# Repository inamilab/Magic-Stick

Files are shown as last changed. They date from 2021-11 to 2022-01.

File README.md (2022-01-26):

# Rolling Stone Illusion
This project is just a demo for the rolling stone illusion. 

## Hardware
Interface Image



This is the hardware requiered to build a rolling stone stick
- Stick: Any drum stick or aluminium stick is OK
- Microcontroller: Arduino UNO or MEGA is OK. 
- Accelerometer: MPU 6050 (https://www.amazon.co.jp/-/en/MPU-6050-3-Axis-Gyroscope-Acceleration-Sensor/dp/B008BOPN40)
- Audio Amplifier: Hapbeat Amplifier. (but any audio amplifier is OK) 
- Vibrator, serveral actuators can be used:
    - Hapbeat motor (not good)
    - ALPS transducers (available in the lab) GOOD
    - Haptuator (also available at the lab) NOT TESTED YET

### Connection PINs (Arduino pro mini)

Arduino Mini Pro pinout

Arduino PIN | Conection
--- | ---
SCL (pin D21) |  Accelerometer SCL pin
SDA (pin D20) |  Accelerometer SDA pin
GND  |  Accelerometer GND
5V  |  Accelerometer 5V
Audio PWM (pin D11)  |  Hapbeat audio IN (L/R)
GND  |  Hapbeat audio GND

## Software
To install some Arduino libraries are needed to make the software run: 
- Mozzi (https://sensorium.github.io/Mozzi/)
- MPU 6050 non block IC2 libraries (included in the project)
- MPU Arduino libraries, for the accelerometer calibration (https://github.com/jrowberg/i2cdevlib)

Note. Since audio synthesis needs to run as fast as possible, it is not possible to use the usual MPU 6050 Arduino libraries. Non block libraries to read the acceleromter data are needed for the code run smoothly. 

### Accelerometer calibration 
It is mandatory to calibrate the MPU 6050 sensor in order to get accurate tilt angle readings. Otherwise the reading will drift or be unacurate. 

The calibration values for MPU 6050 ARE UNIQUE FOR EVERY SENSOR. The calibration values must be extracted using a script included in the MPU6050 Arduino libraries (https://github.com/jrowberg/i2cdevlib/blob/master/Arduino/MPU6050/examples/IMU_Zero/IMU_Zero.ino).

When running the calibration script, the accelerometer must be placed in a flat surface and it should not be moved. 

The calibration values must the introduced in `accel_control.h` in the following constants:
````
#define ACC_X_OFFSET  -1840
#define ACC_Y_OFFSET  -2186
#define ACC_Z_OFFSET  1199
````

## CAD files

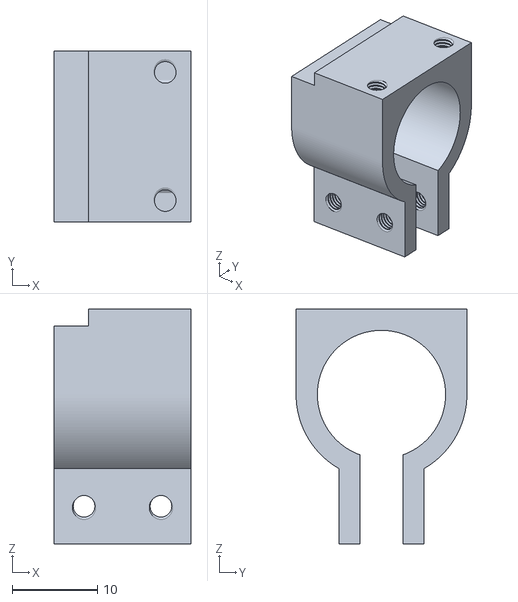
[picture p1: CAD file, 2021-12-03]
drone-stick/models/mpu-base v2.stl
16.0 x 20.0 x 27.5

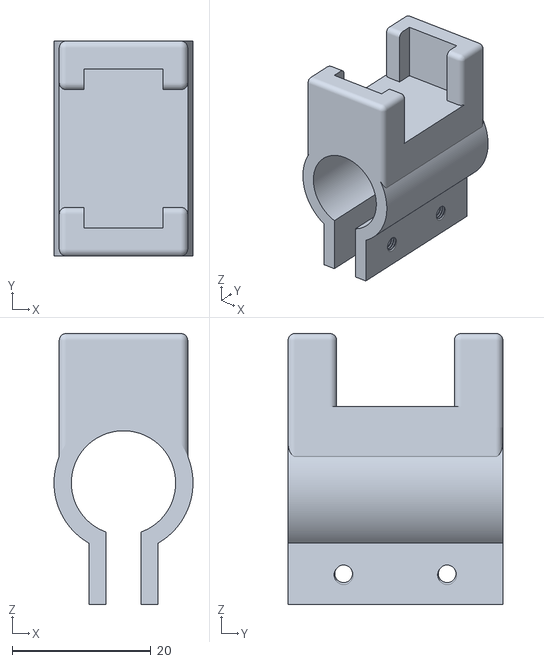
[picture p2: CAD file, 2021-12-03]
drone-stick/models/ALPS haptuator base v4.stl
20.0 x 30.9 x 39.0

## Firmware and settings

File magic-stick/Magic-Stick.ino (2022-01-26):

#include "accel_control.h"  // MPU control (for stick roll and acceleration)
#include <MozziGuts.h>
#include <Oscil.h> // oscillator template
#include "ball_table.h"

#define CONTROL_RATE 256 // Hz, powers of 2 are most reliable

// ================================================================
// ===                      INITIAL SETUP                       ===
// ================================================================

float acc=0; float p_acc=0;  // simulated marbel acceleration
float vel=0; float p_vel=0;  // simulated marbel velocity
float dist=1.0; float p_dist=1.0;  // simulated marbel distance
const float LEN = 0.6; //2.0; //stick lenght in m
const float LEN_MM = 600; //2000; //stick lenght in mm
const float H = 1.0/256.0;  // drag simulation teime step in seconds
const float HH = 0.4; // impact simulation time step in seconds (the smaller the larger the decay time)
// variables to control the impact decay rate
float impact_vel=0;
float impact_curve = 1;
float i_dist = 0.0;

void setup(){
  Serial.begin(115200);
  while (!Serial) delay(10); // will pause until serial console opens-
  setup_accelero();
  vel = 0.0; acc= 0.0;
  p_vel = 0.0; p_acc=0.0;
  startMozzi(CONTROL_RATE);
}

// function to calculate the marvel impact decay sine wave
void marbelImpact(){
    
  impact_curve = (4*impact_vel * exp(-(i_dist)*(i_dist)));
  i_dist = i_dist + (HH * ((impact_vel )/ 2.0)  );  // HH value was adjusted (but I cannot feel the relation velocity/impact force clearly)
  //dist = p_dist + (H *((p_vel + vel)/2.0 ) );
  if (impact_curve < 0){ impact_curve = 0;}

  // SERIAL DEBUG
  // Serial.print (impact_vel);
  // Serial.print (",");
  // Serial.print (impact_curve);
  // Serial.print (",");
  // Serial.println (i_dist/100.0);
}


// Function when the ball rolls up
void rollingUp(float roll, float az){
  acc = 7.0 * sin(roll);
  //acc = az;

  if (p_dist > LEN){
    if (vel != 0) { impact_vel = vel; i_dist = 0;  }  //impact_vel = vel; i_dist = dist;
    vel = 0;
    marbelImpact();
  }else{
    vel = p_vel + (H * ( (p_acc + acc ) / 2.0 )   ) ;
  }

  dist = p_dist + (H * ((p_vel + vel )/ 2.0)  );
   
  p_acc = acc;
  p_vel = vel;
  p_dist = dist;
}

// Function when the ball rolls DOWN
void rollingDown(double roll, float az){
   float sak = sin(roll);
   if (sak*sak < 0.2) {
    acc = 0;
   }else{
    acc = (9.8*sak - 1.96*(sak*-1)) * sqrt (1- (sak*sak) ) ;
   }

   if (p_dist < 0){
      if (vel != 0)  { impact_vel = -vel;  i_dist = 0;  }  // impact_vel = -vel;  i_dist = LEN;
      vel = 0;  
      marbelImpact();  
   }else{
      vel = p_vel + (H * ( (p_acc + acc ) / 2.0 )   ) ;
   }

   dist = p_dist + (H *((p_vel + vel)/2.0 ) );
   
   p_acc = acc;
   p_vel = vel;
   p_dist = dist;
}


float TILT_LIMIT = DEG_TO_RAD * 1;  
void updateControl(){
  getAccInfo();  // gets the accelerometer info 
  
  if ((tilt_y < 2*PI-TILT_LIMIT) && (tilt_y > PI)){
    rollingDown(tilt_y, accy);
    //Serial.print ("down ");
  }else if ((tilt_y > TILT_LIMIT) && (tilt_y < PI)){
    rollingUp(tilt_y, accy);  
    //Serial.print ("up ");
  }

//  Serial.print (tilt_y);
//  Serial.print (",");
//  Serial.print (acc);
//  Serial.print (",");
//  Serial.print (vel);
//  Serial.print (",");
//  Serial.print (impact_vel);
//  Serial.print (",");
//  Serial.println (dist);

}

int dd = 0;
int index = 0;
int updateAudio(){
  dd =  (int)(dist * 1000);
  if ((dd < 0) || (dd > LEN_MM)){
    dd = (int)(i_dist * 1000);
    index = dd % 30;
    return isinTable8[index] * impact_curve;
    //return isinTable8[0];
  }
  index = dd % 30;
  return isinTable8[index];
}

void loop() {
  audioHook(); // required to be here
}

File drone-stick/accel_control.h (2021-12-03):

#include <twi_nonblock.h>

static volatile byte acc_status = 0;
#define ACC_IDLE 0
#define ACC_READING 1
#define ACC_WRITING 2

int accbytedata[14];

#define MPU6050_ADDR                  0x68
#define MPU6050_SMPLRT_DIV_REGISTER   0x19
#define MPU6050_CONFIG_REGISTER       0x1a
#define MPU6050_GYRO_CONFIG_REGISTER  0x1b
#define MPU6050_ACCEL_CONFIG_REGISTER 0x1c
#define MPU6050_PWR_MGMT_1_REGISTER   0x6b
#define MPU6050_ACCEL_OUT_REGISTER    0x3b
#define TEMP_LSB_2_DEGREE     340.0    // [bit/celsius]
#define TEMP_LSB_OFFSET       12412.0
// Sensor calibration offset values
//-1840  -2186 1199  89  39  29  (my accelerometer values)
#define ACC_X_OFFSET  -1840
#define ACC_Y_OFFSET  -2186
#define ACC_Z_OFFSET  1199

int minVal=265;
int maxVal=402;
int accx_i; int accy_i; int accz_i;
float accx; float accy; float accz;
int xAng; int yAng; int zAng;
double tilt_x; double tilt_y; double tilt_z;

// Writes val to address register on device
void acc_writeTo(byte address, byte val) {
  twowire_beginTransmission(MPU6050_ADDR); // start transmission to device
  twowire_send( address );
  twowire_send( val );
  twowire_endTransmission();
}

// Initial setup of the accelerometer 
void setup_accelero(){
  initialize_twi_nonblock();

  acc_writeTo(MPU6050_SMPLRT_DIV_REGISTER, 0x00);
  acc_writeTo(MPU6050_CONFIG_REGISTER, 0x00);
  acc_writeTo(MPU6050_GYRO_CONFIG_REGISTER, 0x00); //0x08
  acc_writeTo(MPU6050_ACCEL_CONFIG_REGISTER, 0x00);
  acc_writeTo(MPU6050_PWR_MGMT_1_REGISTER, 0x01);
  
  acc_status = ACC_IDLE;
}

/// ---------- non-blocking version ----------
void initiate_read_accelero(){
  // Reads num bytes starting from address register on device in to _buff array
  // set address of targeted slave
  txAddress = MPU6050_ADDR; //MMA7660_ADDR;
  // reset tx buffer iterator vars
  txBufferIndex = 0;
  txBufferLength = 0;

  // put byte in tx buffer
  txBuffer[txBufferIndex] = MPU6050_ACCEL_OUT_REGISTER; // Start reading from register for X
  ++txBufferIndex;
  // update amount in buffer
  txBufferLength = txBufferIndex;

  twi_initiateWriteTo(txAddress, txBuffer, txBufferLength);
  acc_status = ACC_WRITING;
}

void initiate_request_accelero(){
  // reset tx buffer iterator vars
  txBufferIndex = 0;
  txBufferLength = 0;

  byte read = twi_initiateReadFrom(MPU6050_ADDR, 14); // 14 is the number of bytes to read
  acc_status = ACC_READING;
}

void finalise_request_accelero() {
  byte read = twi_readMasterBuffer( rxBuffer, 14 ); 
  // set rx buffer iterator vars
  rxBufferIndex = 0;
  rxBufferLength = read;

  byte i = 0;
  while( rxBufferLength - rxBufferIndex > 0) { // device may send less than requested (abnormal)
    accbytedata[i] = rxBuffer[rxBufferIndex];
    ++rxBufferIndex;
    i++;
  }

  acc_status = ACC_IDLE;
}
/// ----end------ non-blocking version ----------

// Main loop that gets the acc raw data and computes the tild angles
unsigned long ms = millis();
unsigned long readTime = ms;
void getAccInfo(){
  //ms = millis();
  //if (ms > readTime){
  //  readTime += 20;

    switch( acc_status ){
    case ACC_IDLE:
      accx_i = (accbytedata[0] << 8 | accbytedata[1]); // accelerometer x reading, reduced to 8 bit
      accx = (float)(accx_i + ACC_X_OFFSET) / 16384.0;
      accy_i = (accbytedata[2] << 8 | accbytedata[3]); // accelerometer y reading, 8 bit
      accy = (float)(accy_i + ACC_Y_OFFSET) / 16384.0;
      accz_i = (accbytedata[4] << 8 | accbytedata[5]); // accelerometer z reading
      accz = (float)(accz_i + ACC_Z_OFFSET) / 16384.0;
      
//      Serial.print("aX ");Serial.print(accx);
//      Serial.print("\taY ");Serial.print(accy);
//      Serial.print("\taZ ");Serial.print(accz);
//      Serial.println();

      // Method from the tilt arduino sample: https://how2electronics.com/measure-tilt-angle-mpu6050-arduino/#:~:text=The%20MPU6050%20consist%20of%203,shown%20in%20the%20below%20figure.
      // ONLY TILT ANGLE IN X IS NEEDED FOR THE ROLLING STONE DEMO
      xAng = map(accx_i,minVal,maxVal,-90,90);
      yAng = map(accy_i,minVal,maxVal,-90,90);
      zAng = map(accz_i,minVal,maxVal,-90,90);

//      tilt_x= RAD_TO_DEG * (atan2(-yAng, -zAng)+PI);
//      tilt_y= RAD_TO_DEG * (atan2(-xAng, -zAng)+PI);
//      tilt_z= RAD_TO_DEG * (atan2(-yAng, -xAng)+PI);

      tilt_x= (atan2(-yAng, -zAng)+PI);
      tilt_y= (atan2(-xAng, -zAng)+PI);
      tilt_z= (atan2(-yAng, -xAng)+PI);
      
//      Serial.print("x Angle ");Serial.print(tilt_x);
//      Serial.print("\ty Angle ");Serial.print(tilt_y);
//      Serial.print("\tz Angle ");Serial.print(tilt_z);
//      Serial.println();
      
      initiate_read_accelero();      
      break;
    case ACC_WRITING:
      if ( TWI_MTX != twi_state ){
        initiate_request_accelero();
      }
      break;
    case ACC_READING:
      if ( TWI_MRX != twi_state ){
        finalise_request_accelero();
      }
      break;
    }
  //}
}

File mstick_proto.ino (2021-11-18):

#include "accel_control.h"  // MPU control (for stick roll and acceleration)
//#include "sound_contro.h"  

#include <MozziGuts.h>
#include <Oscil.h> // oscillator template
#include <tables/sin2048_int8.h> // sine table for oscillator

#define CONTROL_RATE 256 // Hz, powers of 2 are most reliable
//Oscil <SIN2048_NUM_CELLS, AUDIO_RATE> aSin(SIN2048_DATA);
//float gain;

uint8_t isinTable8[] = { 
   0,  26,  52,  78, 102, 125, 147, 167, 185, 201, 215, 226, 234, 240,
 243, 243, 240, 234, 226, 215, 201, 185, 167, 147, 125, 102,  78,  52,
  26,   0
}; 

// ================================================================
// ===                      INITIAL SETUP                       ===
// ================================================================

void setup(){
  Serial.begin(115200);
  while (!Serial) delay(10); // will pause until serial console opens
  setup_accelero();
  startMozzi(CONTROL_RATE);
  //aSin.setFreq(50);
  //gain = 255;
}

float acc=0; float p_acc=0;
float vel=0; float p_vel=0;
float dist=1.0; float p_dist=1.0; float pp_dist=1.0;
const int LEN = 2; //stick LEN in m
const float H = 1.0/256.0;  // in seconds

// Function when the ball rolls down
void rollingUp(float roll, float az){
  acc = 7.0 * sin(roll);
  //acc = az;

  if ((p_dist < 0) || (p_dist > LEN)){
    vel = 0;
  }else{
    vel = p_vel + (H * ( (p_acc + az ) / 2.0 )   ) ;
  }

  dist = p_dist + (H * ((p_vel + vel )/ 2.0)  );
  if (dist < 0.0){
     dist = 0.0; //acc=0.0; vel = 0.0; 
   }else if (dist > LEN){
     dist = LEN; //acc=0.0; vel = 0.0;
   }
   
  p_acc = acc;
  p_vel = vel;
  p_dist = dist;
}

// Function when the ball rolls DOWN
void rollingDown(double roll, float az){
   float sak = sin(roll);
   if (sak*sak < 0.2) {
    acc = 0;
   }else{
    acc = (9.8*sak - 1.96*(sak*-1)) * sqrt (1- (sak*sak) ) ;
   }

   if ((p_dist < 0) || (p_dist > LEN)){
      vel = 0;
   }else{
      vel = p_vel + (H * ( (p_acc + az ) / 2.0 )   ) ;
   }

   dist = p_dist + (H *((p_vel + vel)/2.0 ) ); 
   if (dist < 0.0){
     dist = 0.0; //acc=0.0; vel = 0.0;  
   }else if (dist > LEN){
     dist = LEN; //acc=0.0; vel = 0.0;
   }
   
   p_acc = acc;
   p_vel = vel;
   p_dist = dist;
}


float TILT_LIMIT = DEG_TO_RAD * 5;  
void updateControl(){
  getAccInfo();  // gets the accelerometer info 

  if ((tilt_x > 2*PI-TILT_LIMIT) && (tilt_x > TILT_LIMIT)){
     vel = 0.0; acc= 0.0;
     p_vel = 0.0; p_acc=0.0;
     //Serial.print("zero ");
  }else if ((tilt_x < 2*PI-TILT_LIMIT) && (tilt_x > PI)){
    rollingDown(tilt_x, accx);
    //Serial.print ("down ");
  }else if ((tilt_x > TILT_LIMIT) && (tilt_x < PI)){
    rollingUp(tilt_x, accx);  
    //Serial.print ("up ");
  }

//  Serial.print (tilt_x);
//  Serial.print (",");
//  Serial.print (acc);
//  Serial.print (",");
//  Serial.print (vel);
//  Serial.print (",");
//  Serial.println (dist);

}

//int updateAudio(){
//  if (dist != pp_dist){
//    pp_dist = dist;
//    return aSin.next() * gain; 
//  }
//  return 0;
//}

int dd = 0;
int index = 0;
int updateAudio(){
  dd =  (int)(dist * 1000);
  index = dd % 30;
  return isinTable8[index];
}

void loop() {
  audioHook(); // required to be here
}

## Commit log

2021-11-18 first commit: working rolling vibration with no impact vibration
    [accel_control.h, mstick_proto.ino]
2021-11-26 bugfix:Vel and dist on boundary conditions, ball drag milestonebut needs debbuging
    [Magic-Stick.ino]
2021-12-01 bugfix: zero tilt bug fix and table volume decrease
    [Magic-Stick.ino]
2021-12-03 feature:adding holders stl files
    [ALPS haptuator base v4.stl, mpu-base v2.stl]
2022-01-26 feature: impact velocity parameters tunning
2022-01-26 moving magic-stick files into a separate folder
    [ALPS haptuator base v4.stl, mpu-base v2.stl]
2022-01-26 feature: creating Drone Stick folder
    [ALPS haptuator base v4.stl, mpu-base v2.stl]
2022-01-26 drone folder rename
    [ALPS haptuator base v4.stl, mpu-base v2.stl]
2022-01-26 bugfix: use positive sine for impact
    [Magic-Stick.ino]
